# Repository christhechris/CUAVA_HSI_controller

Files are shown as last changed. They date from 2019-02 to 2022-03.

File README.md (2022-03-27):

View this project on [CADLAB.io](https://cadlab.io/project/1621). 



# CUAVA_HSI_controller
eCAD of the CUAVA-1 ISTI payload control board.

This project is licensed under a [Creative Commons Attribution 3.0 Australia License](http://creativecommons.org/licenses/by/3.0/au/)

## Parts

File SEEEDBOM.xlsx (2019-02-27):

Designator | MPN/Seeed SKU | Qty | Link
R2 | 301010292 | 1
U2,U3,U5 | 10051922-1510ELF | 3 | https://www.digikey.com.au/product-detail/en/amphenol-icc-fci/10051922-1510ELF/609-1238-1-ND/1003033
R1,R3,R4,R5,R6 | 301010456 | 5
C1,C8 | 302010024 | 2
C2,C3,C4,C5 | 302010178 | 4
J2 | 1473149-4 | 1
C9,C12,C13 | 302010040 | 3
C11,C14 | 302010111 | 2
C6,C7,C10 | CC1206MKX5R5BB476 | 3
U4 | AP7115-25SEG-7 | 1
H1,H2 | TSW-126-07-G-D-LL | 2 | https://au.mouser.com/ProductDetail/Samtec/TSW-126-07-G-D-LL
F1 | MF-MSMF200-2 | 1
U1 | PAM2306AYPKE | 1
L1,L2 | SRN4018-4R7M | 2
USB1 | ZX62-B-5PA | 1
J1 | 614004190021 | 1

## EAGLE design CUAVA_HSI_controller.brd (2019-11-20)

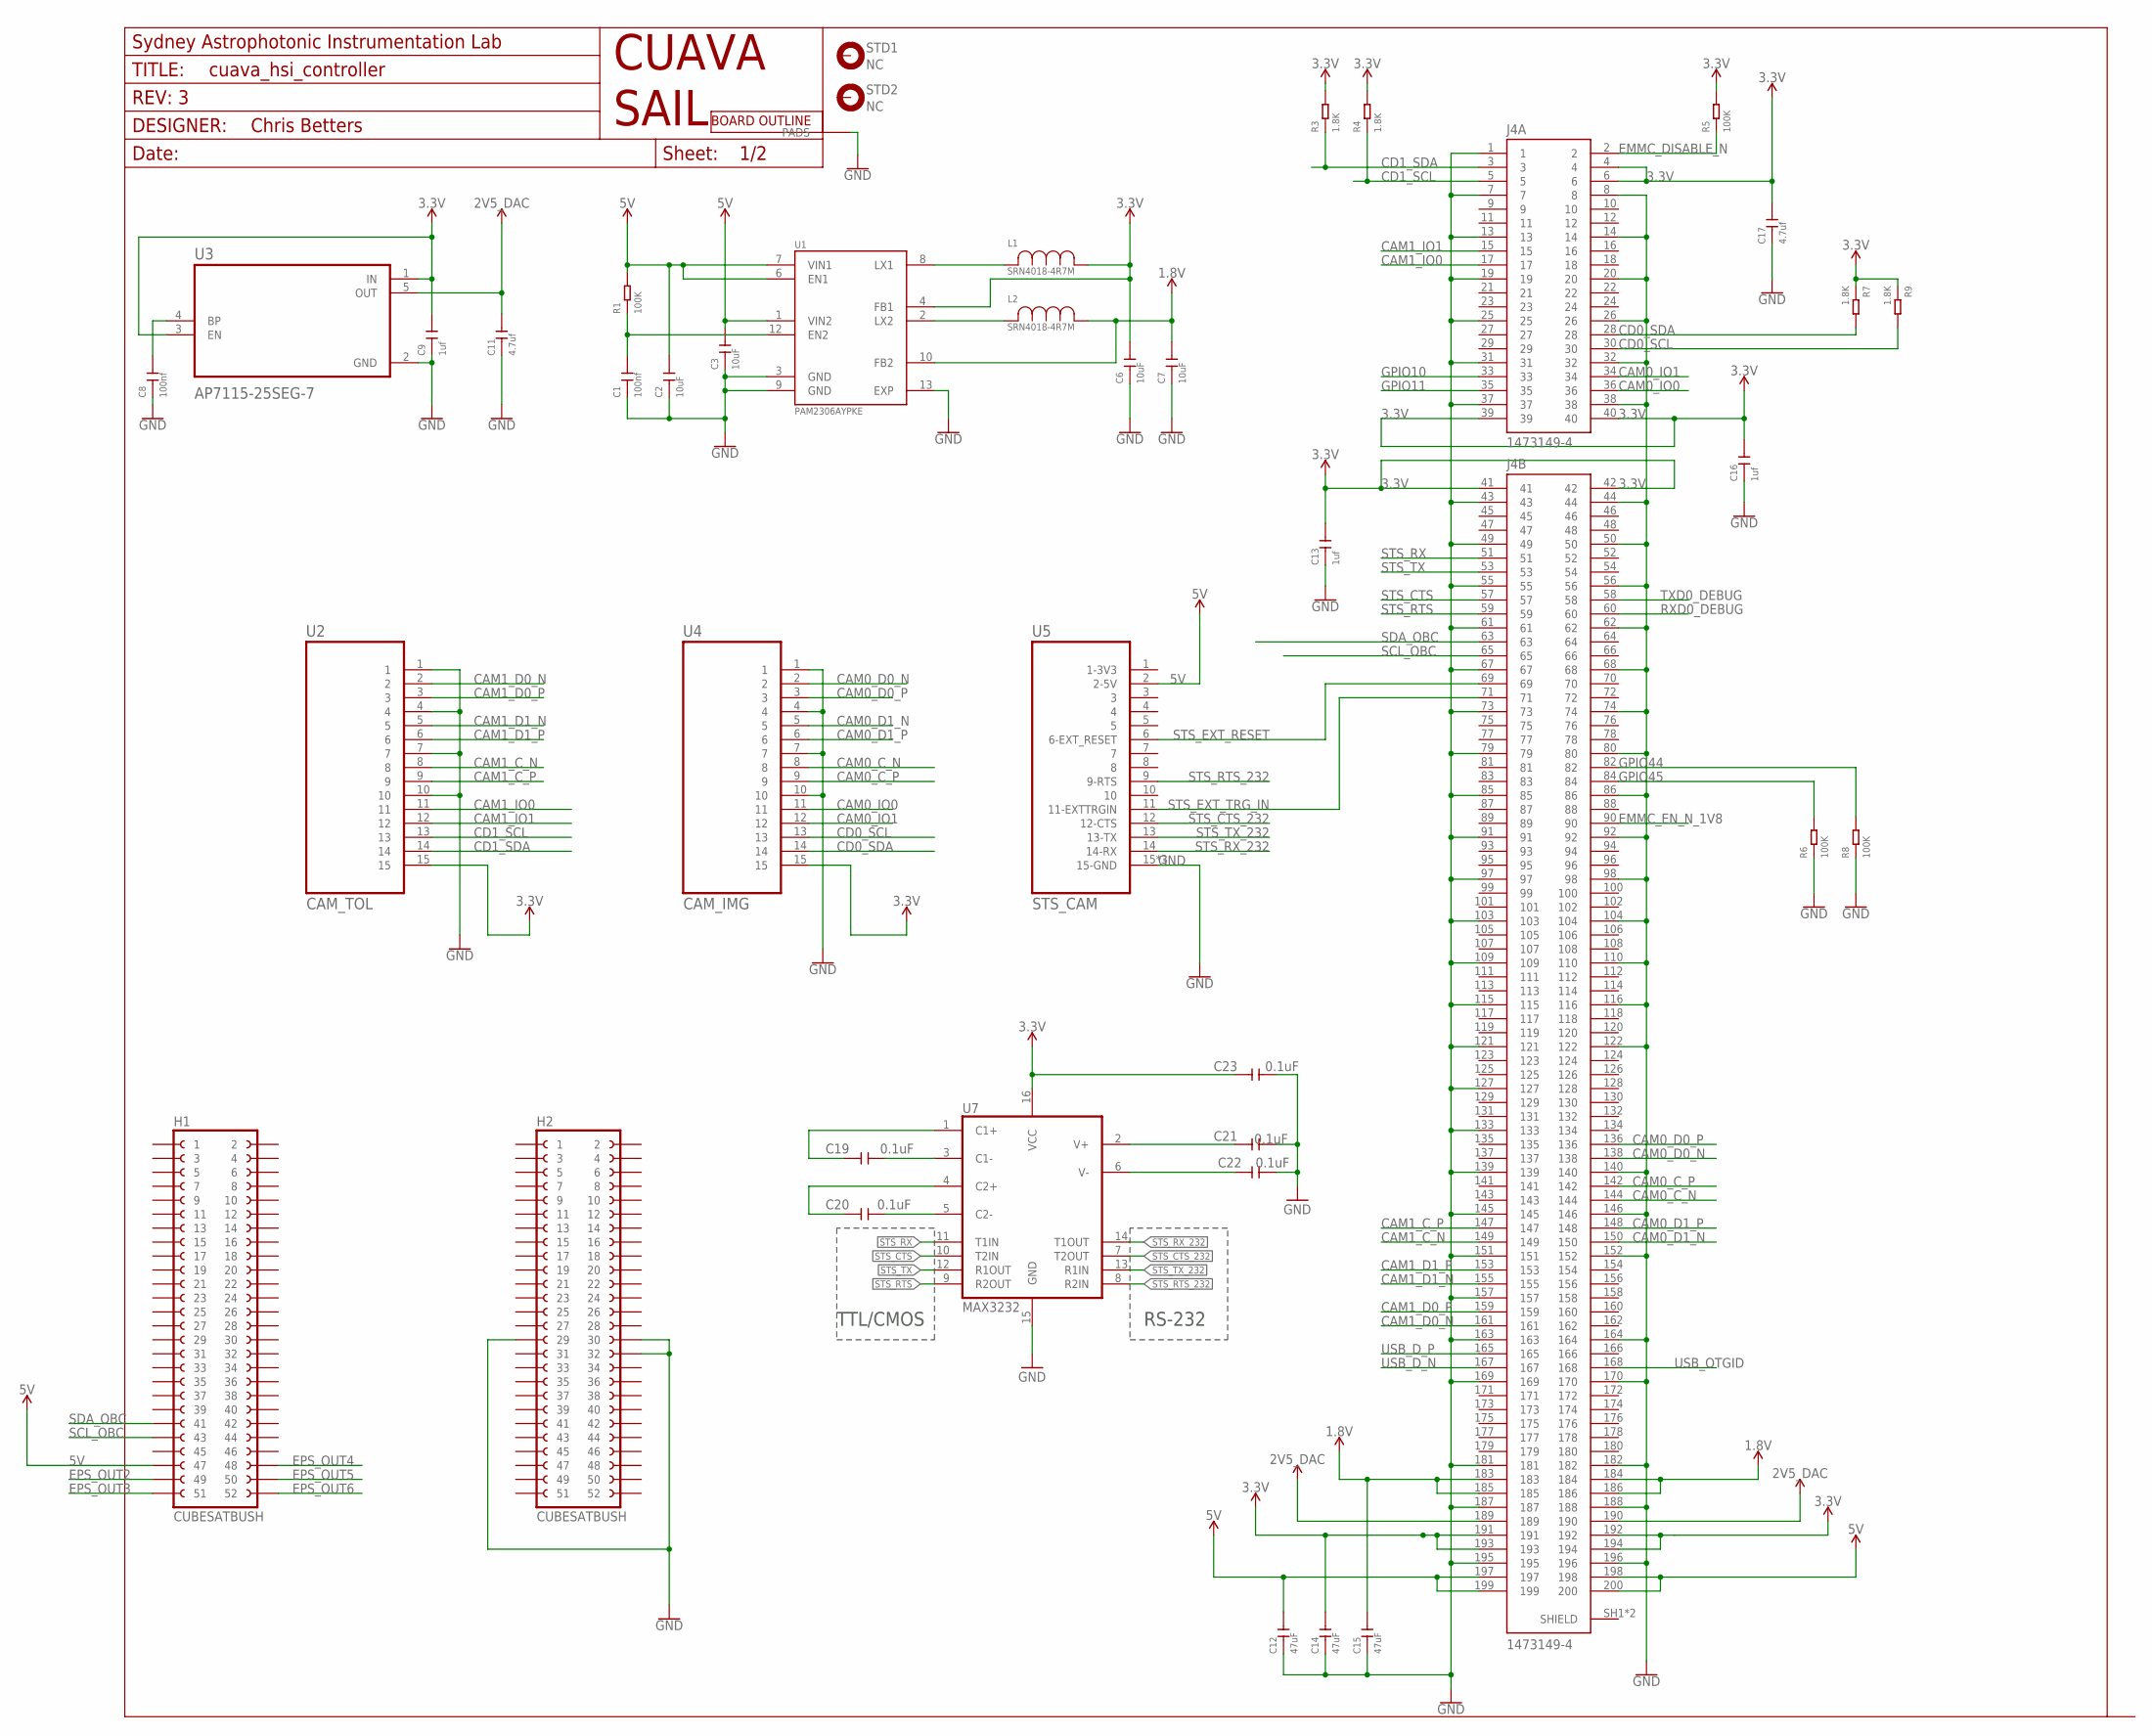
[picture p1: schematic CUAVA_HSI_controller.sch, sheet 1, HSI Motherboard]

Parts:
C1, C8: 100nf; C0402K
C2, C3, C6, C7: 10uF; C3216
C9, C13, C16: 1uf; C0402K
C11, C17: 4.7uf; C0603
C12, C14, C15: 47uF; C3216
C19, C20, C21, C22, C23: 0.1uF; C0402K
EDGE1: CUBESAT_BOARD_OUTLINE
FRAME1: SAIL_FRAMEDEFAULT; SAIL_FRAME_DEFAULT
H1, H2: CUBESATBUSH; 2X26HEADER
J4: 1473149-4; TE_1473149-4
L1, L2: SRN4018-4R7M; IND_BOURNS_SRN4018
LOGO1: CUAVA_LOGO
LOGO2: SAIL_LOGO; SAIL_LOGO_VEC_20MM
R1, R5, R6, R8: 100K; R0402
R3, R4, R7, R9: 1.8K; R0402
STD1, STD2: NC; 3,0-PAD
U1: PAM2306AYPKE; SON45P300X300X80-13N
U2: CAM_TOL; FCI_10051922-1510ELF
U3: AP7115-25SEG-7; SOT65P210X110-5N
U4: CAM_IMG; FCI_10051922-1510ELF
U5: STS_CAM; FCI_10051922-1510ELF
U7: MAX3232; TSSOP16

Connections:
1.8V: C7.2, C15.2, J4.183, J4.184, J4.185, J4.186, L2.1, U1.10 (FB2)
2V5: C11.2, J4.189, J4.190, U3.5 (OUT)
3.3V: C6.2, C9.2, C13.2, C14.2, C16.2, C17.2, C23.1, J4.4, J4.6, J4.39, J4.40, J4.41, J4.42, J4.191, J4.192, J4.193, J4.194, L1.1, R3.2, R4.2, R5.2, R7.1, R9.1, U1.4 (FB1), U2.15, U3.1 (IN), U3.3 (EN), U4.15, U7.16 (VCC)
5V: C2.2, C3.2, C12.2, H1.47, J4.197, J4.198, J4.199, J4.200, R1.2, U1.1 (VIN2), U1.6 (EN1), U1.7 (VIN1), U5.2 (2-5V); also elsewhere on the board
C1+: C19.1, U7.1 (C1+)
C1-: C19.2, U7.3 (C1-)
C2+: C20.1, U7.4 (C2+)
C2-: C20.2, U7.5 (C2-)
CAM0_C_N: J4.144, U4.8
CAM0_C_P: J4.142, U4.9
CAM0_D0_N: J4.138, U4.2
CAM0_D0_P: J4.136, U4.3
CAM0_D1_N: J4.150, U4.5
CAM0_D1_P: J4.148, U4.6
CAM0_IO0: J4.36, U4.11
CAM0_IO1: J4.34, U4.12
CAM1_C_N: J4.149, U2.8
CAM1_C_P: J4.147, U2.9
CAM1_D0_N: J4.161, U2.2
CAM1_D0_P: J4.159, U2.3
CAM1_D1_N: J4.155, U2.5
CAM1_D1_P: J4.153, U2.6
CAM1_IO0: J4.17, U2.11
CAM1_IO1: J4.15, U2.12
CD0_SCL: J4.30, R9.2, U4.13
CD0_SDA: J4.28, R7.2, U4.14
CD1_SCL: J4.5, R4.1, U2.13
CD1_SDA: J4.3, R3.1, U2.14
EMMC_DISABLE_N: J4.2, R5.1
EMMC_EN_N_1V8: J4.90
EN2: C1.2, R1.1, U1.12 (EN2)
EPS_OUT2: H1.49; also elsewhere on the board
EPS_OUT3: H1.51
EPS_OUT4: H1.48; also elsewhere on the board
EPS_OUT5: H1.50; also elsewhere on the board
EPS_OUT6: H1.52; also elsewhere on the board
GND: C1.1, C2.1, C3.1, C6.1, C7.1, C8.1, C9.1, C11.1, C12.1, C13.1, C14.1, C15.1, C16.1, C17.1, C21.2, C22.2, C23.2, EDGE1.P$1, EDGE1.P$2, EDGE1.P$3, EDGE1.P$4, H2.29, H2.30, H2.32, J4.1, J4.7, J4.8, J4.13, J4.14, J4.19, J4.20, J4.25, J4.26, J4.31, J4.32, J4.37, J4.38, J4.43, J4.44, J4.49, J4.50, J4.55, J4.56, J4.61, J4.62, J4.67, J4.68, J4.73, J4.74, J4.79, J4.80, J4.85, J4.86, J4.91, J4.92, J4.97, J4.98, J4.103, J4.104, J4.109, J4.110, J4.115, J4.116, J4.121, J4.122, J4.127, J4.133, J4.139, J4.140, J4.145, J4.146, J4.151, J4.152, J4.157, J4.163, J4.164, J4.169, J4.170, J4.181, J4.182, J4.187, J4.188, J4.195, J4.196, R6.1, R8.1, U1.3 (GND), U1.9 (GND), U1.13 (EXP), U2.1, U2.4, U2.7, U2.10, U3.2 (GND), U4.1, U4.4, U4.7, U4.10, U5.15 (15-GND), U5.16 (15-GND), U5.17 (15-GND), U7.15 (GND); also elsewhere on the board
GPIO10: J4.33
GPIO11: J4.35
GPIO44: J4.82, R8.2
GPIO45: J4.84, R6.2
LX1: L1.2, U1.8 (LX1)
LX2: L2.2, U1.2 (LX2)
unnamed: C8.2, U3.4 (BP)
RXD0_DEBUG: J4.60; also elsewhere on the board
SCL_OBC: H1.43, J4.65; also elsewhere on the board
SDA_OBC: H1.41, J4.63; also elsewhere on the board
STS_CTS: J4.57, U7.10 (T2IN)
STS_CTS_232: U5.12 (12-CTS), U7.7 (T2OUT)
STS_EXT_RESET: J4.69, U5.6 (6-EXT_RESET)
STS_EXT_TRG_IN: J4.71, U5.11 (11-EXTTRGIN)
STS_RTS: J4.59, U7.9 (R2OUT)
STS_RTS_232: U5.9 (9-RTS), U7.8 (R2IN)
STS_RX: J4.51, U7.11 (T1IN)
STS_RX_232: U5.14 (14-RX), U7.14 (T1OUT)
STS_TX: J4.53, U7.12 (R1OUT)
STS_TX_232: U5.13 (13-TX), U7.13 (R1IN)
TXD0_DEBUG: J4.58; also elsewhere on the board
USB_D_N: J4.167; also elsewhere on the board
USB_D_P: J4.165; also elsewhere on the board
USB_OTGID: J4.168
V+: C21.1, U7.2 (V+)
V-: C22.1, U7.6 (V-)

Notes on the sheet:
RS-232
TTL/CMOS

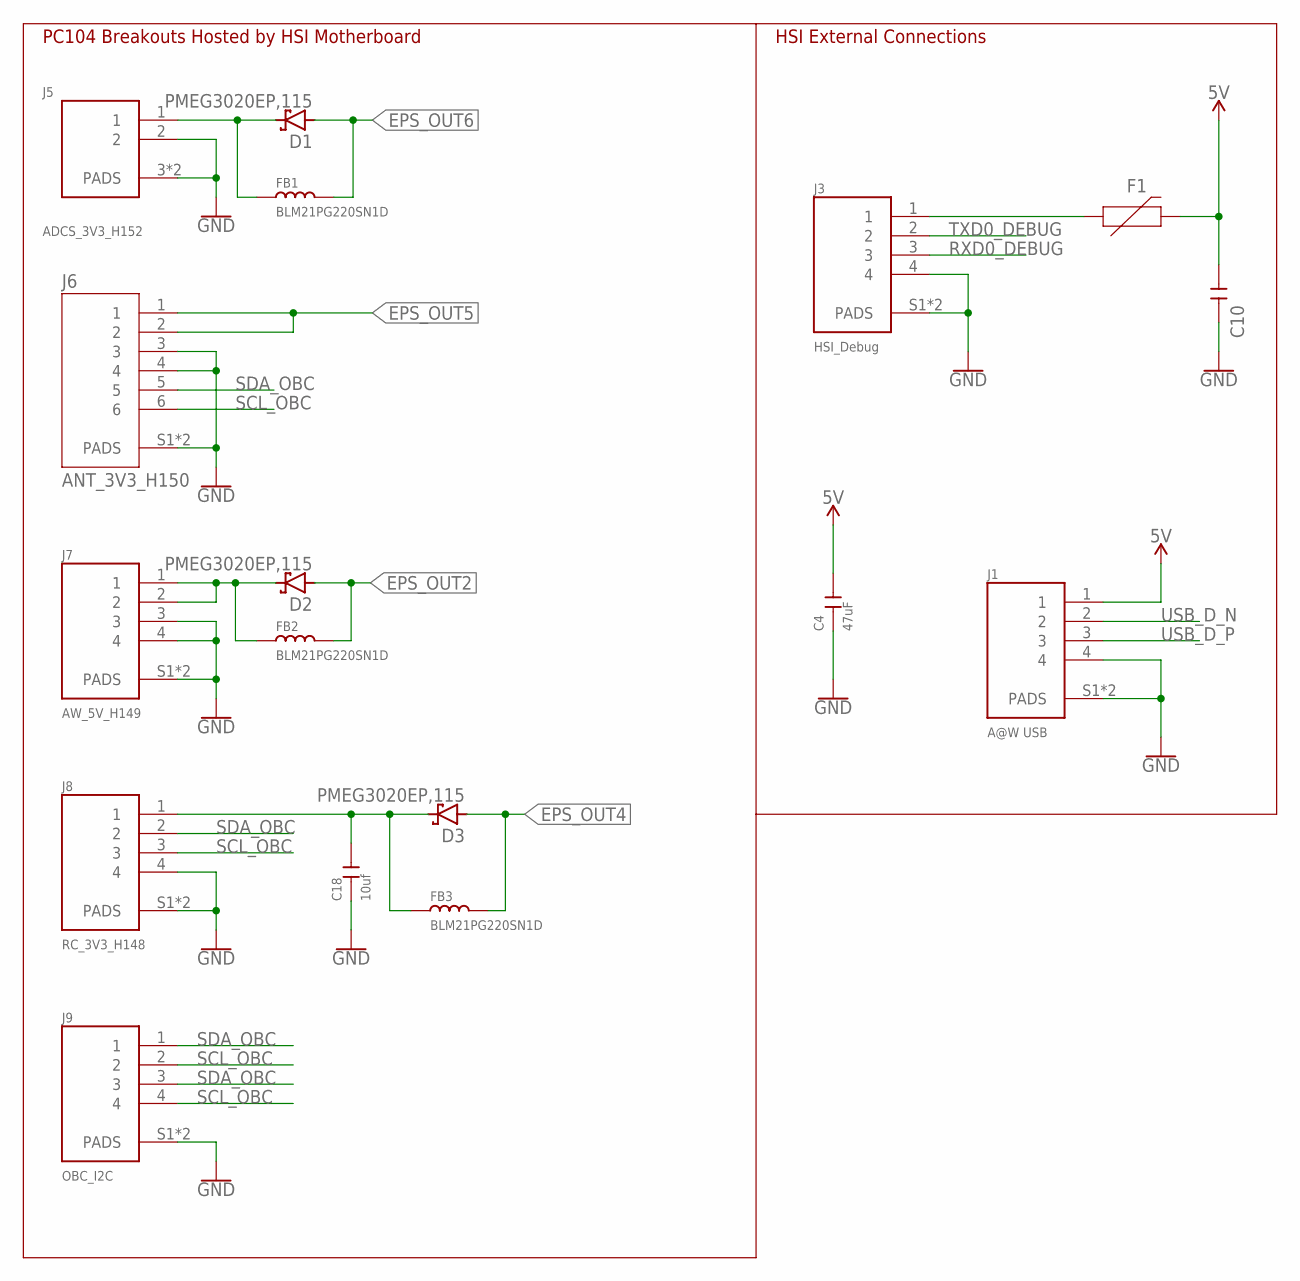
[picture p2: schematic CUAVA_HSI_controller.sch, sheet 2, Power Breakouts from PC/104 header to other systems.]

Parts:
C4, C10: 47uF; C3216
C18: 10uf; C2012
D1, D2, D3: PMEG3020EP,115; SODFL4725X110N
F1: MF-MSMF200-2; FUSM4632X85
FB1, FB2, FB3: BLM21PG220SN1D; C0805
J1: A@W USB; MOLEX_0532610471
J3: HSI_Debug; MOLEX_0532610471
J5: ADCS_3V3_H152; MOLEX_0532610271
J6: ANT_3V3_H150; MOLEX_0532610671
J7: AW_5V_H149; MOLEX_0532610471
J8: RC_3V3_H148; MOLEX_0532610471
J9: OBC_I2C; MOLEX_0532610471

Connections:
5V: C4.2, C10.1, F1.2, J1.1; also elsewhere on the board
A@W_5V0: D2.C, FB2.1, J7.1, J7.2
ADCS_3V3: D1.C, FB1.1, J5.1
EPS_OUT2: D2.A, FB2.2; also elsewhere on the board
EPS_OUT4: D3.A, FB3.2; also elsewhere on the board
EPS_OUT5: J6.1, J6.2; also elsewhere on the board
EPS_OUT6: D1.A, FB1.2; also elsewhere on the board
GND: C4.1, C10.2, C18.1, J1.4, J1.S1 (PADS), J1.S2 (PADS), J3.4, J3.S1 (PADS), J3.S2 (PADS), J5.2, J5.3 (PADS), J5.4 (PADS), J6.3, J6.4, J6.S1 (PADS), J6.S2 (PADS), J7.3, J7.4, J7.S1 (PADS), J7.S2 (PADS), J8.4, J8.S1 (PADS), J8.S2 (PADS), J9.S1 (PADS), J9.S2 (PADS); also elsewhere on the board
HSI_DEBUG_V: F1.1, J3.1
RC_3V3: C18.2, D3.C, FB3.1, J8.1
RXD0_DEBUG: J3.3; also elsewhere on the board
SCL_OBC: J6.6, J8.3, J9.2, J9.4; also elsewhere on the board
SDA_OBC: J6.5, J8.2, J9.1, J9.3; also elsewhere on the board
TXD0_DEBUG: J3.2; also elsewhere on the board
USB_D_N: J1.2; also elsewhere on the board
USB_D_P: J1.3; also elsewhere on the board

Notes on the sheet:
PC104 Breakouts Hosted by HSI Motherboard
HSI External Connections

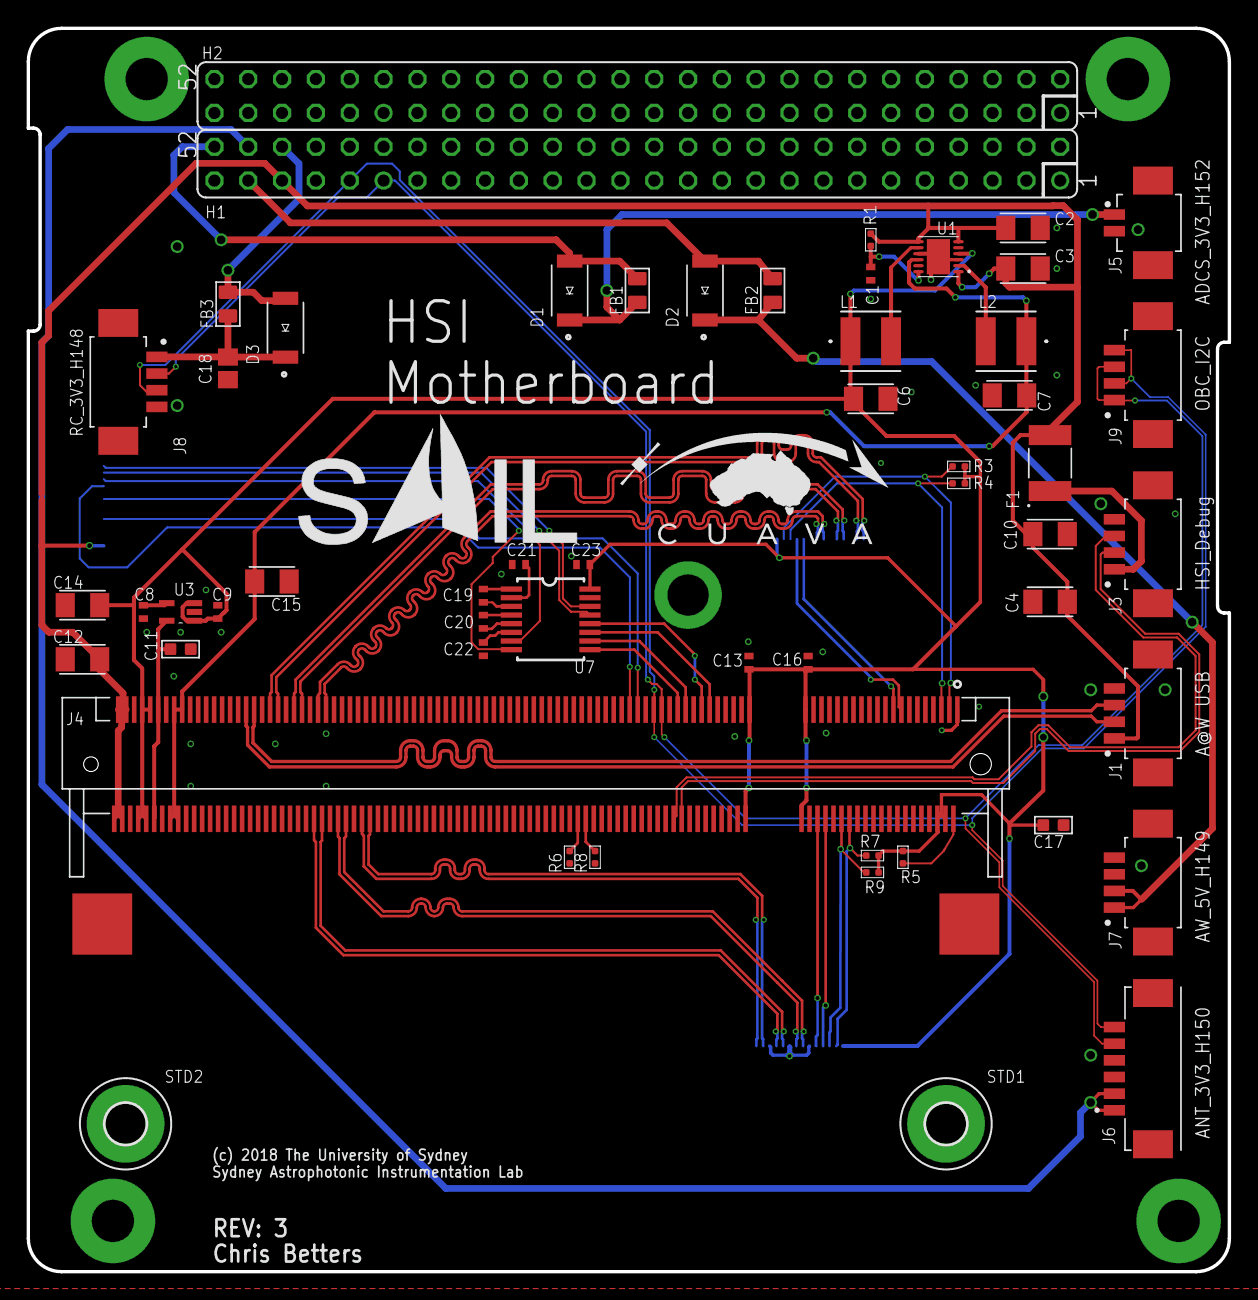
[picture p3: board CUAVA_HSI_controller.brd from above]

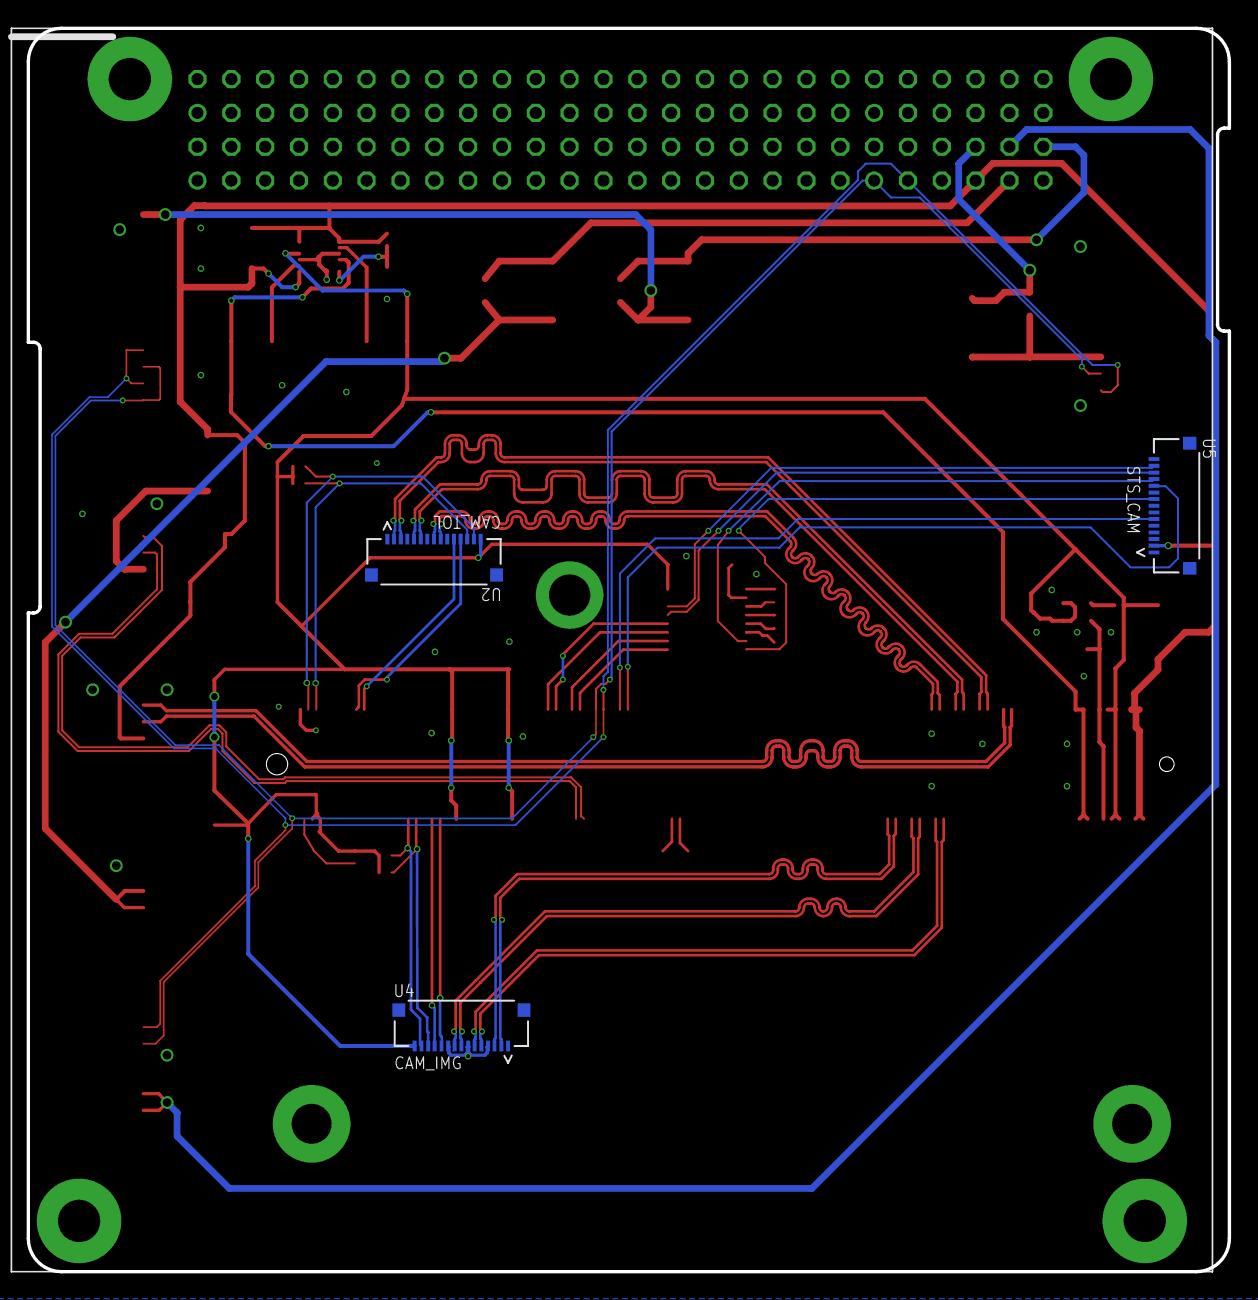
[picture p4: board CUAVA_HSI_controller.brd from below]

Board: 4 copper layers, 90.2 x 93.3 mm, 61 parts (4 on the bottom side), 62 nets.

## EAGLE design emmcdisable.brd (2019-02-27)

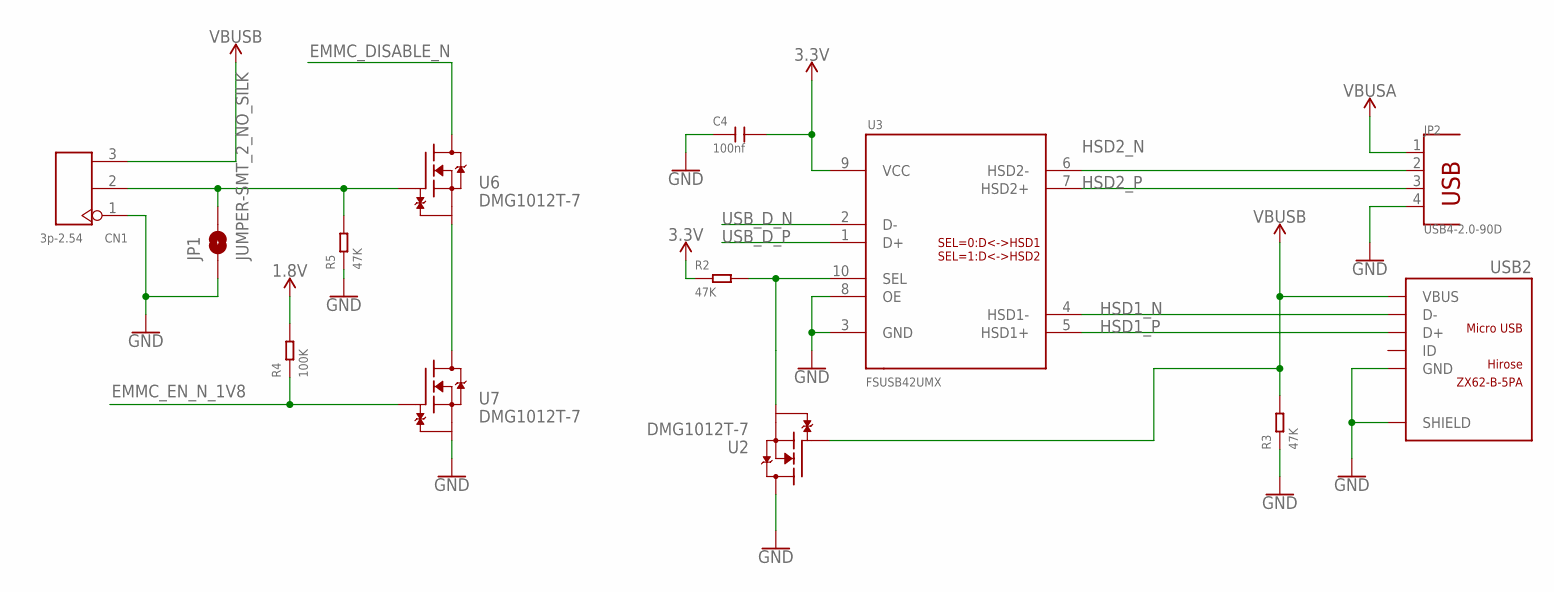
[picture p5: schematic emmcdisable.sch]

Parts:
C4: 100nf; C0402K
CN1: 3p-2.54; H3-2.54
JP1: JUMPER-SMT_2_NO_SILK; SMT-JUMPER_2_NO_SILK
JP2: USB4-2.0-90D; USB4+2P-2.0-90D
R2, R3, R5: 47K; R0402
R4: 100K; R0402
U2, U6, U7: DMG1012T-7; SOT50P175X90-3N
U3: FSUSB42UMX; QFN40P140X180X55-10
USB2: ZX62-B-5PA; MICRO-USB5+6P-SMD-0.65-AB

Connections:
1.8V: R4.2
3.3V: C4.2, R2.1, U3.9 (VCC)
EMMC_DISABLE_N: U6.D
EMMC_EN_N_1V8: R4.1, U7.G
GND: C4.1, CN1.1, JP1.1, JP2.4, R3.1, R5.1, U2.D, U3.3 (GND), U3.8 (OE), U7.S, USB2.5 (GND), USB2.P1 (SHIELD), USB2.P2 (SHIELD), USB2.P3 (SHIELD), USB2.P4 (SHIELD), USB2.P5 (SHIELD), USB2.P6 (SHIELD)
HSD1_N: U3.4 (HSD1-), USB2.2 (D-)
HSD1_P: U3.5 (HSD1+), USB2.3 (D+)
HSD2_N: JP2.2, U3.6 (HSD2-)
HSD2_P: JP2.3, U3.7 (HSD2+)
unnamed: CN1.2, JP1.2, R5.2, U6.G
unnamed: U6.S, U7.D
SEL: R2.2, U2.S, U3.10 (SEL)
USB_D_N: U3.2 (D-)
USB_D_P: U3.1 (D+)
VBUSA: JP2.1
VBUSB: CN1.3, R3.2, U2.G, USB2.1 (VBUS)

Board: 2 copper layers, 13 parts (0 on the bottom side), 11 nets, no tracks yet.

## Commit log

2019-02-27 init commit
    [CUAVA_HSI_controller.brd, CUAVA_HSI_controller.sch, HSA_case_base.DXF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]
2019-02-27 fix ignores
    [HSA_case_base.DXF]
2019-03-20 - remove camera and i2c swtich. - add STS connector and wire to serial
    [CUAVA_HSI_controller.brd, CUAVA_HSI_controller.sch]
2019-04-15 add alt OBC interface via SPI to i2C bridge
    [CUAVA_HSI_controller.brd, CUAVA_HSI_controller.sch]
2019-04-18 ordered - https://factory.macrofab.com/order/10x65av/overview
    [CUAVA_HSI_controller.brd, CUAVA_HSI_controller.sch]
2019-08-22 - adding break out connecting for rad counter, air wave power backup, and HSI debug breakout - removing SPI option
    [CUAVA_HSI_controller.brd, CUAVA_HSI_controller.sch]
2019-11-19 - rs232 converter for spec. - adjust breakouts for sat
    [CUAVA_HSI_controller.brd, CUAVA_HSI_controller.sch]
2019-11-20 - ordered version Macrofab order r6rnxag
    [CUAVA_HSI_controller.brd, CUAVA_HSI_controller.sch]

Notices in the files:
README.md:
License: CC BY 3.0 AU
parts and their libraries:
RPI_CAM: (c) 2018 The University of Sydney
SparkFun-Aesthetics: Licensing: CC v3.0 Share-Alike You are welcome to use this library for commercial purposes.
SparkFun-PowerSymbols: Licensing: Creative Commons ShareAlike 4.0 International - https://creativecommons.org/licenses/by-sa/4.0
